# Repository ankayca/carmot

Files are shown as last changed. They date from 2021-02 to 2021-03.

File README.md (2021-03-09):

# Carmot
This is an open source esp32s2 board project.
Carmot: The substance believed to be the main ingredient of the Philosopher's Stone.

# Aim
Design a board which will be a miles stone of IOT projects. This board will be IOT 's arduino. So who want to learn IOT apps with proffesional techniques (like use led strip, motor, relay ).

# Note for collaborators :

I am an elecktrical electronic engineer and I work on this to create a different perspective of IOT. I need help to designing board and programming (I am using esp-idf). If you agree to work together , I guarantee that we will change this IOT ecosystem together.

If you have the experience or motivation to will be expert of this zones:
            (pcb design,
            internet protocols(TCP-IP , websocket,udp , etc.),
            esp-idf ,
            circuit design)
            I will feel honor to work with you.
# Contact: 
  email :ankayca2121@gmail.com

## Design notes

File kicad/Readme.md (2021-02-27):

# Notes:
26_02_21.kicad_pcb : revision 2.1
test_fixed_unconnected_wires.kicad_pcb : revision 1.0

test_fixed_unconnected_wires.kicad_pcb work perfectly.

# Important
At 26_02_21.kicad_pcb we try to design more cheapest board to everyone can easily generate and start to be a philosopher of Carmot. 

### Regards from carmot !!!!

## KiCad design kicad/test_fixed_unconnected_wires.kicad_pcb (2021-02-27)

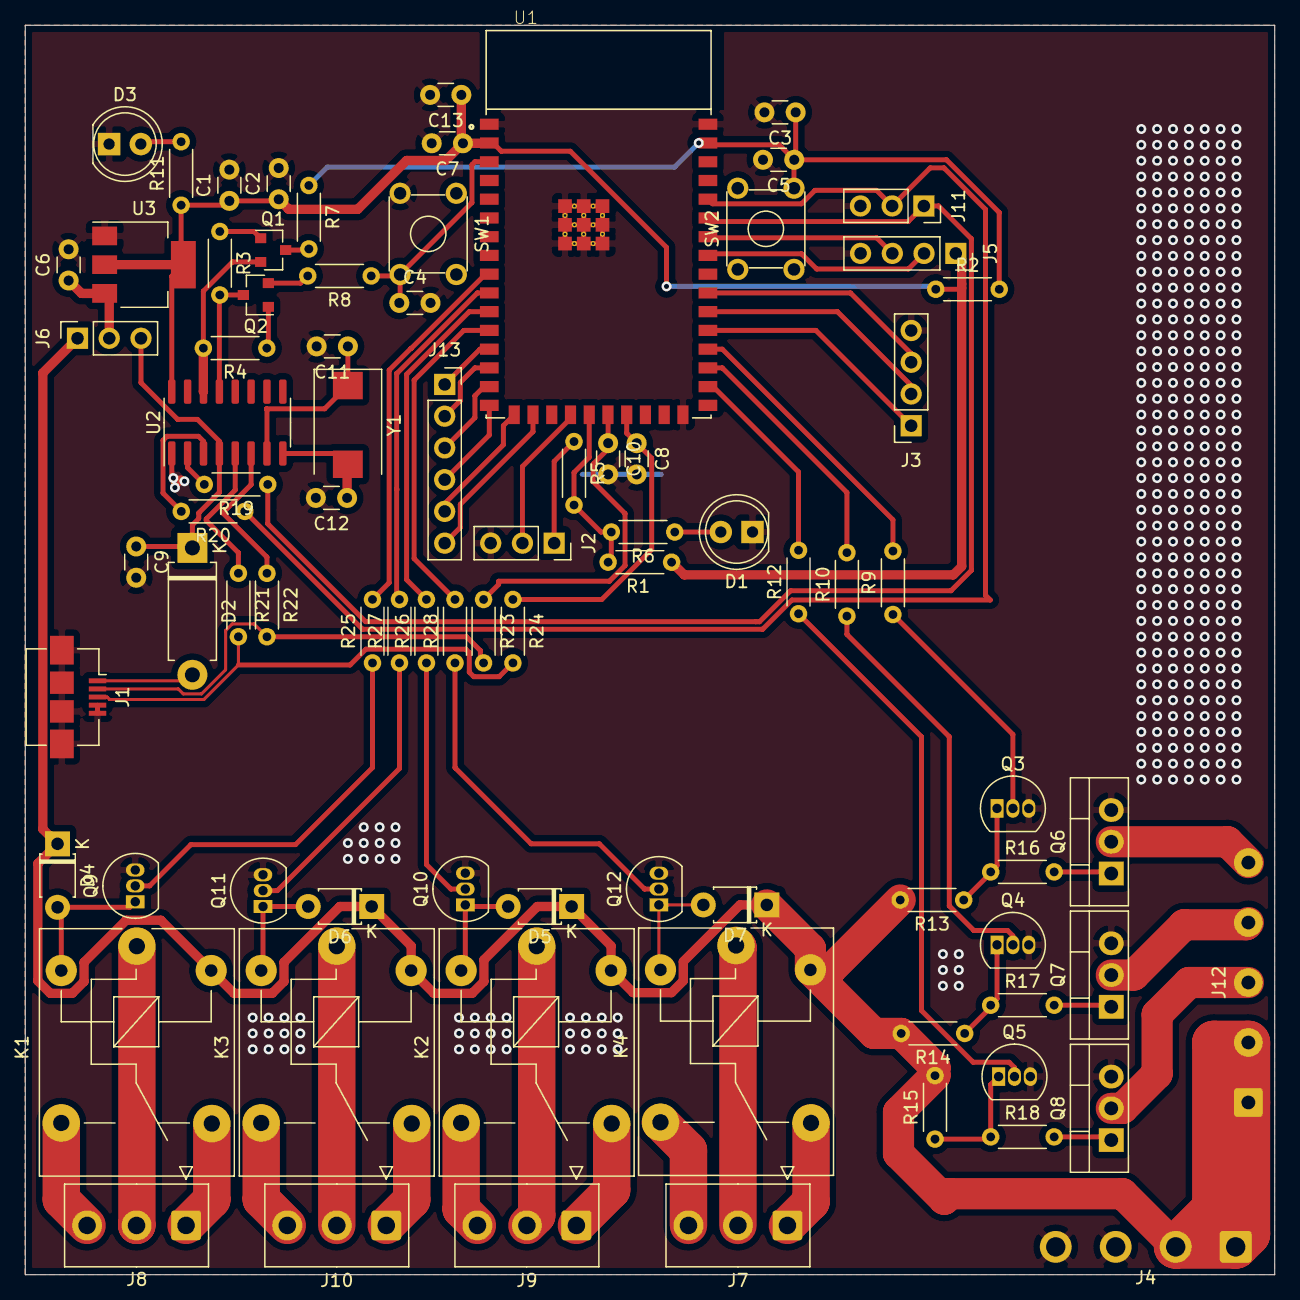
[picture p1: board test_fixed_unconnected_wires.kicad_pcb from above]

Board: 2 copper layers, 100.0 x 100.0 mm, 83 parts (0 on the bottom side), 81 nets.

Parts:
C1: 10uF/25V; C_Disc_D3.0mm_W1.6mm_P2.50mm
C2: 0.1uF/16V; C_Disc_D3.0mm_W1.6mm_P2.50mm
C3: 1uf/10V; C_Disc_D3.0mm_W1.6mm_P2.50mm
C4, C5: 0.1uF; C_Disc_D3.0mm_W1.6mm_P2.50mm
C6, C13: 100nF; C_Disc_D3.0mm_W1.6mm_P2.50mm
C7: 22uF; C_Disc_D3.0mm_W1.6mm_P2.50mm
C8, C10, C11, C12: 22pF; C_Disc_D3.0mm_W1.6mm_P2.50mm
C9: 10uF; C_Disc_D3.0mm_W1.6mm_P2.50mm
D1: LED_GREEN; LED_D5.0mm
D2: 1N5819; D_DO-15_P10.16mm_Horizontal
D3: RED_LED; LED_D5.0mm
D4, D5, D6, D7: 1N4148; D_T-1_P5.08mm_Horizontal
J1: USB_B_Micro; USB_Micro-B_Amphenol_10104110_Horizontal
J2, J11: Conn_01x03_Female; PinSocket_1x03_P2.54mm_Vertical
J3: Conn_01x04_Male; PinSocket_1x04_P2.54mm_Vertical
J4: Conn_01x04_Female; SolderWire-0.75sqmm_1x04_P4.8mm_D1.25mm_OD2.3mm
J5: Conn_01x04_Female; PinSocket_1x04_P2.54mm_Vertical
J6: Conn_01x03_Male; PinSocket_1x03_P2.54mm_Vertical
J7, J8, J9, J10: Conn_01x03_Female; TE_826576-3_1x03_P3.96mm_Vertical
J12: Conn_01x05_Female; SolderWire-0.5sqmm_1x05_P4.8mm_D0.9mm_OD2.3mm
J13: Conn_01x06_Male; PinSocket_1x06_P2.54mm_Vertical
K1, K2, K3, K4: SANYOU_SRD_Form_C; Relay_SPDT_SANYOU_SRD_Series_Form_C
Q1, Q2: BC817; SOT-23
Q3, Q4, Q5, Q9, Q10, Q11, Q12: BC547; TO-92_Inline
Q6, Q7, Q8: IRLZ44N; TO-220-3_Vertical
R1, R2, R3, R4: 10K; R_Axial_DIN0204_L3.6mm_D1.6mm_P5.08mm_Horizontal
R5, R6, R19, R20, R21, R22, R23, R24: 0; R_Axial_DIN0204_L3.6mm_D1.6mm_P5.08mm_Horizontal
R7, R8: 0R; R_Axial_DIN0204_L3.6mm_D1.6mm_P5.08mm_Horizontal
R9, R10, R12: 5K; R_Axial_DIN0204_L3.6mm_D1.6mm_P5.08mm_Horizontal
R11: 5.1K; R_Axial_DIN0204_L3.6mm_D1.6mm_P5.08mm_Horizontal
R13, R14, R15, R25, R26, R27, R28: 1K; R_Axial_DIN0204_L3.6mm_D1.6mm_P5.08mm_Horizontal
R16, R17, R18: 200R; R_Axial_DIN0204_L3.6mm_D1.6mm_P5.08mm_Horizontal
SW1, SW2: SW_Push_Open_Dual; SW_TH_Tactile_Omron_B3F-10xx
U1: ESP32-S2-WROOM; XCVR_ESP32-S2-WROOM
U2: CH340G; SOIC-16_3.9x9.9mm_P1.27mm
U3: AMS1117-3.3; SOT-223-3_TabPin2
Y1: 12Mhz; Crystal_SMD_FOX_FE-2Pin_7.5x5.0mm

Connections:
+3V3: C1.1, C2.1, C7.1, C13.1, J5.1, R1.2, R2.1, R11.1, U1.2, U2.16, U3.2
+5V: C9.1, D2.1, J6.3, U2.4
+12V: D4.1, D5.1, D6.1, D7.1, J4.1, J4.2, J6.1, J12.1, J12.2, K1.5, K2.5, K3.5, K4.5, R13.2, R14.2, R15.2
CHIP_PU: C3.1, C5.1, R2.2, R7.1, SW2.4, U1.41
DTR: Q2.3, R3.2, U2.13
EN_Auto: Q1.3, R7.2
GND: C1.2, C2.2, C3.2, C4.2, C5.2, C6.2, C7.2, C8.2, C9.2, C10.2, C11.2, C12.2, C13.2, D1.1, D3.1, J1.4, J1.5, J1.6, J2.3, J3.4, J4.3, J4.4, J5.4, J11.3, Q3.3, Q4.3, Q5.3, Q6.3, Q7.3, Q8.3, Q9.3, Q10.3, Q11.3, Q12.3, SW1.3, SW2.3, U1.1, U1.26, U1.42, U1.43.1, U1.43.2, U1.43.3, U1.43.4, U1.43.5, U1.43.6, U1.43.7, U1.43.8, U1.43.9, U1.43.10, U1.43.11, U1.43.12, U1.43.13, U1.43.14, U1.43.15, U1.43.16, U1.43.17, U1.43.18, U1.43.19, U1.43.20, U1.43.21, U2.1, U3.1
GPIO0: C4.1, R8.1, SW1.4, U1.3
GPIO6: R25.2, U1.9
GPIO7: R27.2, U1.10
GPIO8: R26.2, U1.11
GPIO9: R28.2, U1.12
GPIO10: J13.1, U1.13
GPIO11: J13.2, U1.14
GPIO12: J13.3, U1.15
GPIO13: J13.4, U1.16
GPIO14: J13.5, U1.17
GPIO15: J13.6, U1.18
GPIO18: R1.1, R5.2, R6.2, U1.21
GPIO19: C10.1, R23.1, U1.22
GPIO20: C8.1, R24.1, U1.23
GPIO34: R12.2, U1.28
GPIO35: R10.2, U1.29
GPIO36: R9.2, U1.30
GPIO37: J3.1, U1.31
GPIO38: J3.2, U1.32
GPIO39: J3.3, U1.33
IO0_Auto: Q2.2, R8.2
LED_B: J12.5, Q6.2
LED_G: J12.3, Q8.2
LED_R: J12.4, Q7.2
unnamed: C11.1, U2.7, Y1.1
unnamed: C12.1, U2.8, Y1.2
unnamed: D1.2, R6.1
unnamed: D2.2, J1.1
unnamed: D3.2, R11.2
unnamed: D4.2, K1.2, Q9.1
unnamed: D5.2, K2.2, Q10.1
unnamed: D6.2, K3.2, Q11.1
unnamed: D7.2, K4.2, Q12.1
unnamed: J1.2, R22.2, R23.2
unnamed: J1.3, R21.2, R24.2
unnamed: Q1.1, R3.1
unnamed: Q2.1, R4.1
unnamed: Q3.1, R13.1, R16.1
unnamed: Q3.2, R9.1
unnamed: Q4.1, R14.1, R17.1
unnamed: Q4.2, R10.1
unnamed: Q5.1, R15.1, R18.1
unnamed: Q5.2, R12.1
unnamed: Q6.1, R16.2
unnamed: Q7.1, R17.2
unnamed: Q8.1, R18.2
unnamed: Q9.2, R25.1
unnamed: Q10.2, R26.1
unnamed: Q11.2, R27.1
unnamed: Q12.2, R28.1
unnamed: R19.2, U2.2
unnamed: R20.2, U2.3
RTS: Q1.2, R4.2, U2.14
RXD0: J11.2, R20.1, U1.38
RXD1: J2.1, R5.1
Rly1_1: J10.2, K3.1
Rly1_2: J10.1, K3.4
Rly1_3: J10.3, K3.3
Rly2_1: J9.2, K2.1
Rly2_2: J9.1, K2.4
Rly2_3: J9.3, K2.3
Rly3_1: J8.2, K1.1
Rly3_2: J8.1, K1.4
Rly3_3: J8.3, K1.3
Rly4_1: J7.2, K4.1
Rly4_2: J7.1, K4.4
Rly4_3: J7.3, K4.3
SCL: J5.3, U1.36
SDA: J5.2, U1.35
TXD0: J11.1, R19.1, U1.37
TXD1: J2.2, U1.20
USB_DN: R22.1, U2.6
USB_DP: R21.1, U2.5
VCC: C6.1, J6.2, U3.3

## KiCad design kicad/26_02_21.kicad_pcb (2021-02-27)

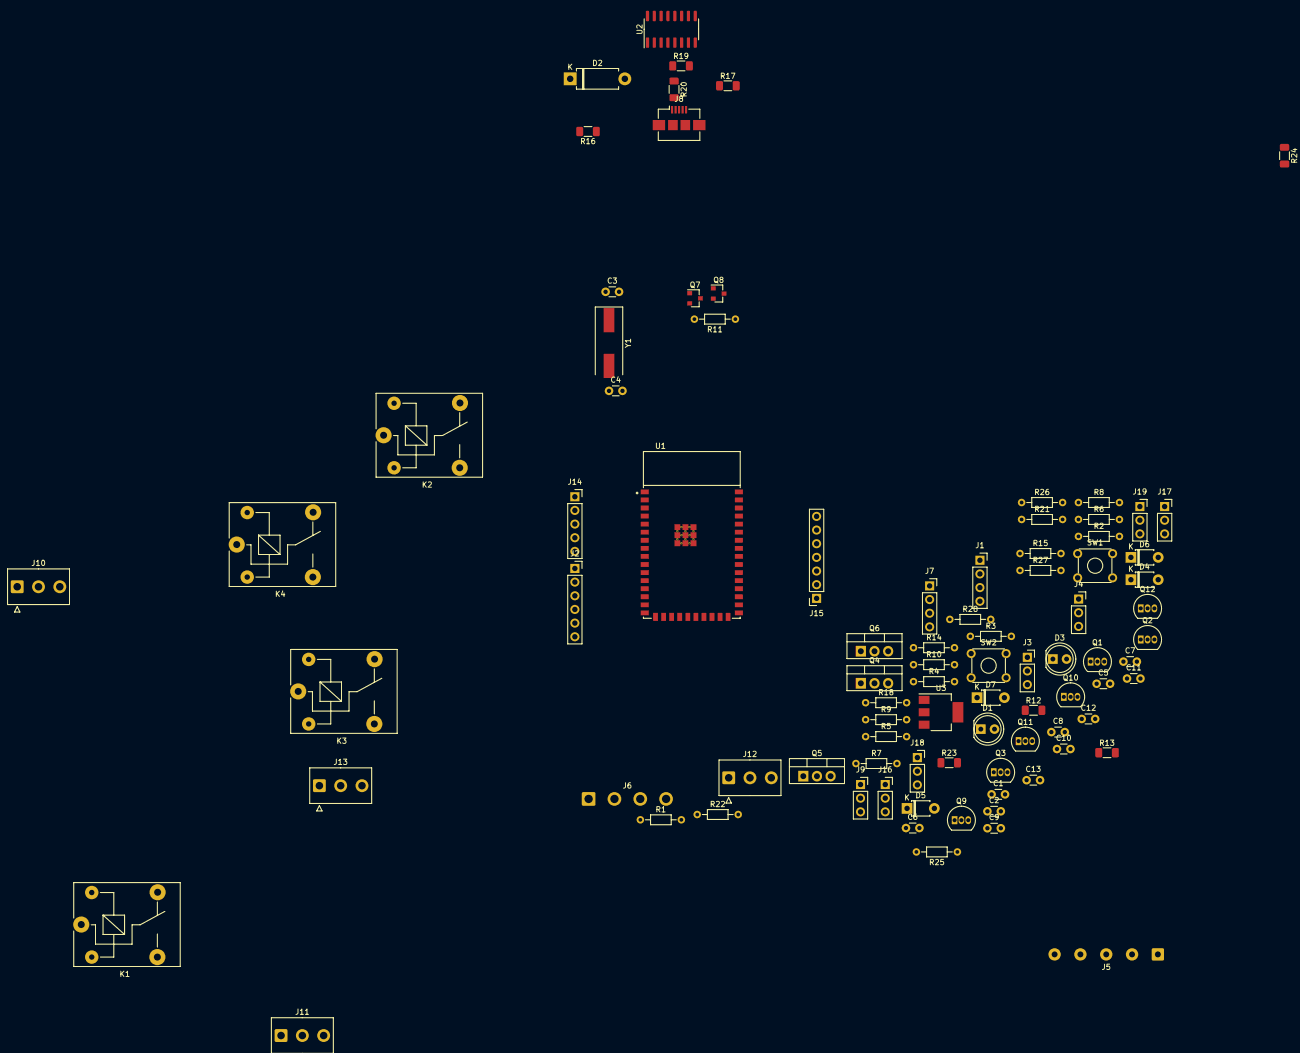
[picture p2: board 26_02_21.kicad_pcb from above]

Board: 2 copper layers, 89 parts (0 on the bottom side), 93 nets, no tracks yet.

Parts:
C1: 22uF; C_Disc_D3.0mm_W1.6mm_P2.50mm
C2, C5, C6: 0.1uF; C_Disc_D3.0mm_W1.6mm_P2.50mm
C3, C4, C12, C13: 22pF; C_Disc_D3.0mm_W1.6mm_P2.50mm
C7, C9: 10uf; C_Disc_D3.0mm_W1.6mm_P2.50mm
C8: 1uf/10V; C_Disc_D3.0mm_W1.6mm_P2.50mm
C10: 10uF; C_Disc_D3.0mm_W1.6mm_P2.50mm
C11: 100nF; C_Disc_D3.0mm_W1.6mm_P2.50mm
D1: LED_GREEN; LED_D5.0mm
D2: 1N5819; D_DO-15_P10.16mm_Horizontal
D3: RED_LED; LED_D5.0mm
D4, D5, D6, D7: 1N4148; D_T-1_P5.08mm_Horizontal
J1: Conn_01x04_Male; PinSocket_1x04_P2.54mm_Vertical
J2: Conn_01x06_Male; PinSocket_1x06_P2.54mm_Vertical
J3, J4: Conn_01x03_Female; PinSocket_1x03_P2.54mm_Vertical
J5: Conn_01x05_Female; SolderWire-0.5sqmm_1x05_P4.8mm_D0.9mm_OD2.3mm
J6: Conn_01x04_Female; SolderWire-0.75sqmm_1x04_P4.8mm_D1.25mm_OD2.3mm
J7: Conn_01x04_Female; PinSocket_1x04_P2.54mm_Vertical
J8: USB_B_Micro; USB_Micro-B_Amphenol_10104110_Horizontal
J9, J16, J17, J18, J19: Conn_01x03_Male; PinSocket_1x03_P2.54mm_Vertical
J10, J11, J12, J13: Conn_01x03_Female; TE_826576-3_1x03_P3.96mm_Vertical
J14: Conn_01x05_Male; PinSocket_1x05_P2.54mm_Vertical
J15: Conn_01x07_Male; PinSocket_1x07_P2.54mm_Vertical
K1, K2, K3, K4: SANYOU_SRD_Form_C; Relay_SPDT_SANYOU_SRD_Series_Form_C
Q1, Q2, Q3, Q9, Q10, Q11, Q12: BC547; TO-92_Inline
Q4, Q5, Q6: IRLZ44N; TO-220-3_Vertical
Q7, Q8: BC817; SOT-23
R1, R2, R3: 5K; R_Axial_DIN0204_L3.6mm_D1.6mm_P7.62mm_Horizontal
R4, R5, R6, R25, R26, R27, R28: 1K; R_Axial_DIN0204_L3.6mm_D1.6mm_P7.62mm_Horizontal
R7, R8, R9: 200R; R_Axial_DIN0204_L3.6mm_D1.6mm_P7.62mm_Horizontal
R10, R11, R18, R21: 10K; R_Axial_DIN0204_L3.6mm_D1.6mm_P7.62mm_Horizontal
R12, R13, R16, R17, R19, R20, R23, R24: 0; R_1206_3216Metric_Pad1.30x1.75mm_HandSolder
R14, R15: 0R; R_Axial_DIN0204_L3.6mm_D1.6mm_P7.62mm_Horizontal
R22: 5.1K; R_Axial_DIN0204_L3.6mm_D1.6mm_P7.62mm_Horizontal
SW1, SW2: SW_Push_Open_Dual; SW_TH_Tactile_Omron_B3F-10xx
U1: ESP32-S2-WROOM; XCVR_ESP32-S2-WROOM
U2: CH340G; SOIC-16_3.9x9.9mm_P1.27mm
U3: AMS1117-3.3; SOT-223-3_TabPin2
Y1: 12Mhz; Crystal_SMD_HC49-SD

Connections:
+3V3: C1.1, C2.1, C9.1, C11.1, J7.1, J17.1, J17.2, J17.3, R18.2, R21.1, R22.1, U1.2, U2.4, U2.16, U3.2
+5V: C10.1, D2.1, D4.1, D5.1, D6.1, D7.1, J9.3, J16.1, J16.2, J16.3, K1.5, K2.5, K3.5, K4.5
+12V: J5.1, J5.2, J6.1, J6.2, J9.1, J18.1, J18.2, J18.3, R4.2, R5.2, R6.2
CHIP_PU: C6.1, C8.1, R14.1, R21.2, SW2.1, SW2.2, U1.41
DTR: Q8.3, R10.2, U2.13
EN_Auto: Q7.3, R14.2
GND: C1.2, C2.2, C3.2, C4.2, C5.2, C6.2, C7.2, C8.2, C9.2, C10.2, C11.2, C12.2, C13.2, D1.1, D3.1, J3.3, J4.3, J6.3, J6.4, J7.4, J8.4, J8.5, J8.6, J19.1, J19.2, J19.3, Q1.3, Q2.3, Q3.3, Q4.3, Q5.3, Q6.3, Q9.3, Q10.3, Q11.3, Q12.3, SW1.3, SW1.4, SW2.3, SW2.4, U1.1, U1.26, U1.42, U1.43.1, U1.43.2, U1.43.3, U1.43.4, U1.43.5, U1.43.6, U1.43.7, U1.43.8, U1.43.9, U1.43.10, U1.43.11, U1.43.12, U1.43.13, U1.43.14, U1.43.15, U1.43.16, U1.43.17, U1.43.18, U1.43.19, U1.43.20, U1.43.21, U2.1, U3.1
GPIO0: C5.1, R15.1, SW1.1, SW1.2, U1.3
GPIO1: J14.1, U1.4
GPIO2: J14.2, U1.5
GPIO3: J14.3, U1.6
GPIO4: J14.4, U1.7
GPIO5: J14.5, U1.8
GPIO6: R25.2, U1.9
GPIO7: R27.2, U1.10
GPIO8: R26.2, U1.11
GPIO9: R28.2, U1.12
GPIO10: J2.1, U1.13
GPIO11: J2.2, U1.14
GPIO12: J2.3, U1.15
GPIO13: J2.4, U1.16
GPIO14: J2.5, U1.17
GPIO15: J2.6, U1.18
GPIO16: J15.1, U1.19
GPIO18: R12.2, R13.2, R18.1, U1.21
GPIO19: C12.1, R23.1, U1.22
GPIO20: C13.1, R24.1, U1.23
GPIO21: J15.2, U1.24
GPIO26: J15.3, U1.25
GPIO33: J15.4, U1.27
GPIO34: R3.2, U1.28
GPIO35: R2.2, U1.29
GPIO36: R1.2, U1.30
GPIO37: J1.1, U1.31
GPIO38: J1.2, U1.32
GPIO39: J1.3, U1.33
GPIO40: J1.4, J15.5, U1.34
GPIO45: J15.6, U1.39
GPIO46: J15.7, U1.40
IO0_Auto: Q8.2, R15.2
LED_B: J5.5, Q4.2
LED_G: J5.3, Q6.2
LED_R: J5.4, Q5.2
unnamed: C3.1, U2.7, Y1.1
unnamed: C4.1, U2.8, Y1.2
unnamed: D1.2, R13.1
unnamed: D2.2, J8.1
unnamed: D3.2, R22.2
unnamed: D4.2, K1.2, Q9.1
unnamed: D5.2, K2.2, Q10.1
unnamed: D6.2, K3.2, Q11.1
unnamed: D7.2, K4.2, Q12.1
unnamed: J8.2, R20.2, R23.2
unnamed: J8.3, R19.2, R24.2
unnamed: Q1.1, R4.1, R7.1
unnamed: Q1.2, R1.1
unnamed: Q2.1, R5.1, R8.1
unnamed: Q2.2, R2.1
unnamed: Q3.1, R6.1, R9.1
unnamed: Q3.2, R3.1
unnamed: Q4.1, R7.2
unnamed: Q5.1, R8.2
unnamed: Q6.1, R9.2
unnamed: Q7.1, R10.1
unnamed: Q8.1, R11.1
unnamed: Q9.2, R25.1
unnamed: Q10.2, R26.1
unnamed: Q11.2, R27.1
unnamed: Q12.2, R28.1
unnamed: R16.2, U2.2
unnamed: R17.2, U2.3
RTS: Q7.2, R11.2, U2.14
RXD0: J4.2, R16.1, U1.38
RXD1: J3.1, R12.1
Rly1_1: J13.2, K3.1
Rly1_2: J13.1, K3.4
Rly1_3: J13.3, K3.3
Rly2_1: J12.2, K2.1
Rly2_2: J12.1, K2.4
Rly2_3: J12.3, K2.3
Rly3_1: J11.2, K1.1
Rly3_2: J11.1, K1.4
Rly3_3: J11.3, K1.3
Rly4_1: J10.2, K4.1
Rly4_2: J10.1, K4.4
Rly4_3: J10.3, K4.3
SCL: J7.3, U1.36
SDA: J7.2, U1.35
TXD0: J4.1, R17.1, U1.37
TXD1: J3.2, U1.20
USB_DN: R20.1, U2.6
USB_DP: R19.1, U2.5
VCC: C7.1, J9.2, U3.3
